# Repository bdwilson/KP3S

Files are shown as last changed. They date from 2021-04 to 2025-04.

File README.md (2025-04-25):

# warning: this repository has been deprecated as I no longer own a KP3S. 

# Kingroon KP3S 

<b>For general documentation/upgrades, please go here: https://bubba.org/kp3s</b>

# Marlin v2.x for Kingroon KP3S
Thanks to @olavgm for his work on 2.0.7 : https://github.com/olavgm/marlin-kp3s 

I've  changed the `configuration.h` and `configuration_adv.h` files and provided those in the different version folders/Marlin directories.

* Support for *BLTouch* has been added
* Babystepping added (but babystepping automatically updates z offset, so make sure to save once you have your z offset the way you want it). To use this, start a print, go into Settings -> Tune -> Z probe offset. 
* You'll need to turn your LCD sideways using [this](https://www.thingiverse.com/thing:4578390) print, or just turn your head sideways. I've chosen to do this since I use Octoprint and also have a magnetic camera mounted to where this LCD screen would overhang.  

A version <b>without</b> bltouch support has been added. I have not tested it,
but feel free to report any issues. It has mesh bed leveling enabled. You can
find it
[here](https://github.com/bdwilson/KP3S/tree/main/releases/2.1.1/no-bltouch).

## Installation
1. Follow the guidance here on installing and connecting: https://bubba.org/kp3s/3dTouch/
2. To install, copy Robin_nano.bin to in the root of an FAT32-formatted SD card.
3. You will need to adjust your Z-Offset (where your printer thinks the bed is in perspective to the extruder tip). Get your favorite bed leveling test print and utilize the Tune -> Z Probe Offset menu (only available after a print has been sent to the printer). You can also adjust this down to zero and slowly decrease it (go towards the negative) if you are worried about damaging your bed.

## Downloading a build
<b>These builds are built using the Titan settings below. If you have a different
setup, you will need to configure your parameters using repetier or
Ocotprint. The changes are mentioned below.</b>

* https://github.com/bdwilson/KP3S/tree/main/releases 

## Building your own.
Grab the configs from [here](https://github.com/bdwilson/KP3S/tree/main/releases) and then use the directions from [TH3D](https://support.th3dstudio.com/hc/downloads/unified-2-firmware/kingroon/kingroon-kp-3s-firmware-kingroon-v1-2-board/), but use this code. 

## Changes needed if you do not have a Titan extruder with mount on the right side 

### KP3S w/ Stock Extruder, BL Touch mounted on left of extruder
1. Mount BL Touch here: [male](https://github.com/bdwilson/KP3S/blob/main/files/BLtouch_Mount-left-male.stl?raw=true) - should be printed with supports & [female](https://github.com/bdwilson/KP3S/blob/main/files/BLtouch_Mount-left-female.stl?raw=true) (original files from here: https://www.thingiverse.com/thing:4609134)
2. Configure your ESTEPS Marlin Motion menu (Control -> Motion -> Steps/mm) -
https://marlinfw.org/docs/features/lcd_menu.html#steps/mm) and Z Probe Offset
via Marlin Prepare menu (Prepare -> Bed Leveling). You cannot change all of the
offsets via marlin, so you may need to use Repetier below. 
<b>You will set your z offset yourself via Marlin menu. If you don't use
the mount above, your offsets WILL be different and you'll need to compile your
own version.</b>
<pre>
#define DEFAULT_AXIS_STEPS_PER_UNIT   { 160, 160, 800, 185 }  // for stock extruder
#define NOZZLE_TO_PROBE_OFFSET { -27, 0, 0 }  // old extruder, mount on left
</pre>
or, you can do this via [Repetier](https://www.repetier.com/download-now/) or
Octoprint via termina:
<pre>
M92 X160 Y160 Z800 E185
M851 X-27 Y0 Z0
</pre>

### KP3S w/ Stock Extruder, BL Touch mounted on left of extruder 
1. Mount for BL Touch is [here](https://www.thingiverse.com/thing:4704668)
2. Configure your ESTEPS Marlin Motion menu (Control -> Motion -> Steps/mm) -
https://marlinfw.org/docs/features/lcd_menu.html#steps/mm) and Z Probe Offset
via Marlin Prepare menu (Prepare -> Bed Leveling). You cannot change all of the
offsets via marlin, so you may need to use Repetier below. 
<b>You will set your z offset yourself via Marlin menu. If you don't use
the mount above, your offsets WILL be different and you'll need to compile your
own version.</b>
<pre>
#define DEFAULT_AXIS_STEPS_PER_UNIT   { 160, 160, 800, 185 }  // for stock extruder
#define NOZZLE_TO_PROBE_OFFSET { -27, -1, 0 }  // old extruder, mount on left
</pre>
or, you can do this via [Repetier](https://www.repetier.com/download-now/) or
Octoprint via terminal:
<pre>
M92 X160 Y160 Z800 E185
M851 X-27 Y0 Z0
</pre>

### KP3S w/ Titan w/ metal enclosure, BL Touch mounted on right of extruder
1. Mount BL Touch using [this mount](https://www.thingiverse.com/thing:4816601)
2. You can download this version directly from me and do not need to make the
modifications below: https://github.com/bdwilson/KP3S/tree/main/releases 
3. Configure your ESTEPS Marlin Motion menu (Control -> Motion -> Steps/mm) -
https://marlinfw.org/docs/features/lcd_menu.html#steps/mm) and Z Probe Offset
via Marlin Prepare menu (Prepare -> Bed Leveling). You cannot change all of the
offsets via marlin, so you may need to use Repetier below. 
<b>You will set your z offset yourself via Marlin menu. If you don't use
the mount above, your offsets WILL be different and you'll need to compile your
own version.</b>
<pre>
#define DEFAULT_AXIS_STEPS_PER_UNIT   { 160, 160, 800, 905 } // for titan 
#define NOZZLE_TO_PROBE_OFFSET { 31, -1, 0 }  // titan extruder mount on right
</pre>
or, you can do this via [Repetier](https://www.repetier.com/download-now/) or
Octoprint via termina:
<pre>
M92 X160 Y160 Z800 E910
M851 X29 Y-1 Z-2.41
</pre>

[\<\< Back to Main KP3S site](https://bubba.org/kp3s)

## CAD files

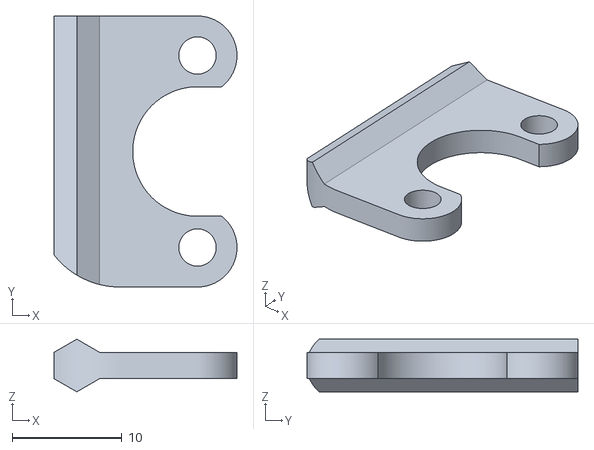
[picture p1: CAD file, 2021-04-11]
files/BLtouch_Mount-left-male.stl
16.7 x 24.7 x 4.80

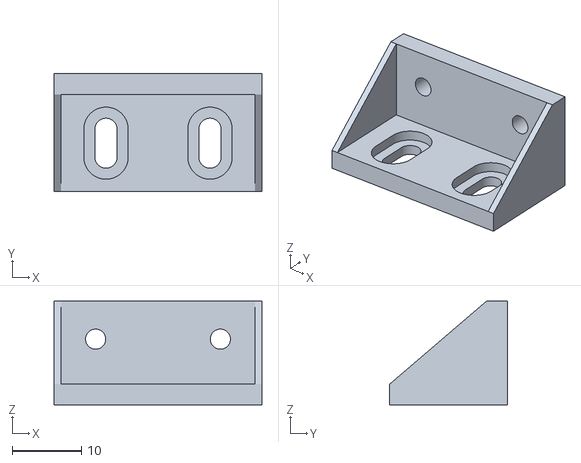
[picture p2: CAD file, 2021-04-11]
files/BLtouch_Mount-right.stl
30.0 x 17.0 x 15.0

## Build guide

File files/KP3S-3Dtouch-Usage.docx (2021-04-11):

KP3S-3Dtouch Using Method

1. Installation

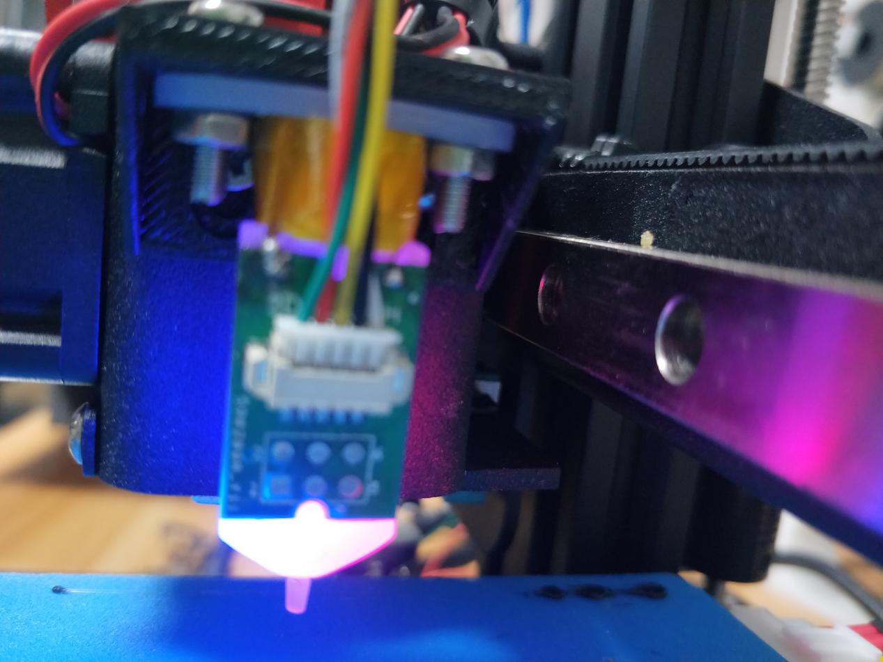
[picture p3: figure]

Fully connect adapter board to the profile. Otherwise,it will not trigger the endstop function if the probe rod of 3D touch is too low.

2. The setting wires of Auto Leveling Sensor
  2.1 Connect Leveling limit wire 2pin to Zmax, please note the order between black wire and white one.

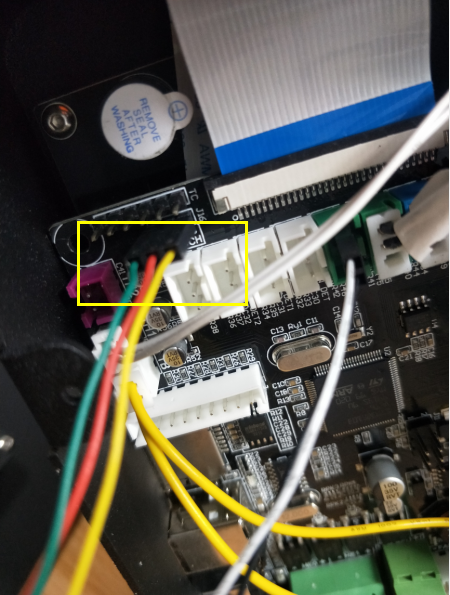
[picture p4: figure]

2.2The order of connecting Servo wires 3pin as following photo. Also, pay attention to the order of wires.

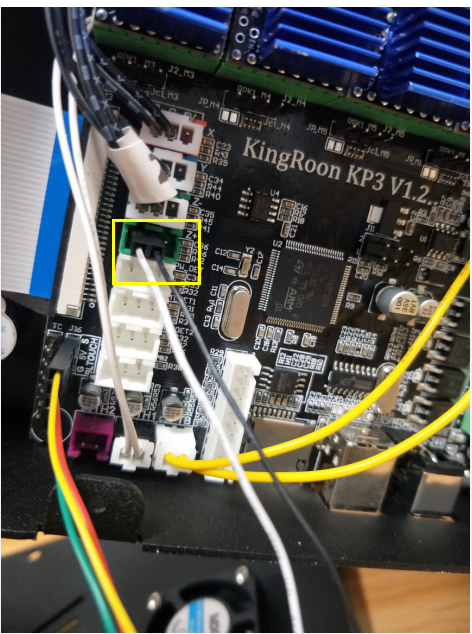
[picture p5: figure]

3.This is the setting of Configuration file

3.1 Change the mode as” cfg_leveling_mode” 1

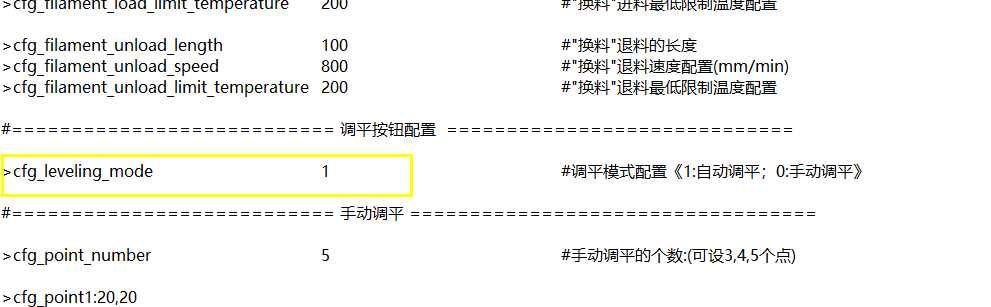
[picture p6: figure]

3.2 Setup it into Z Min_Probe_endstorp_inverting 0 # Z probe

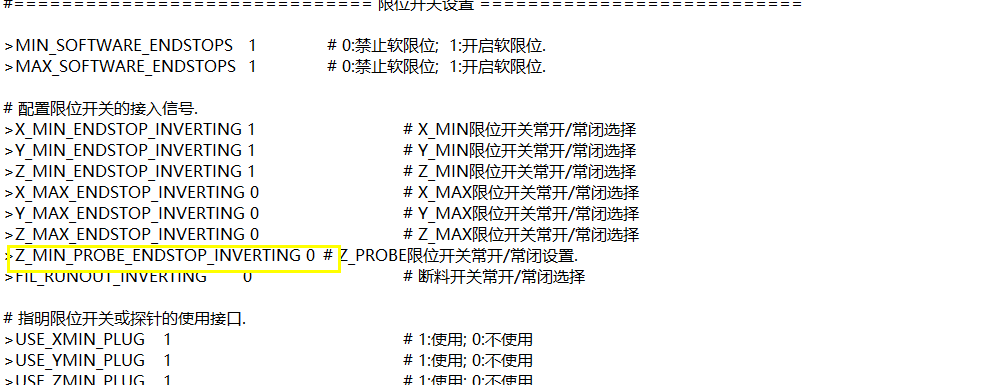
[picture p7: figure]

3.3 About the probe rob on ZmaxZ_min_probe_pin_mode 2

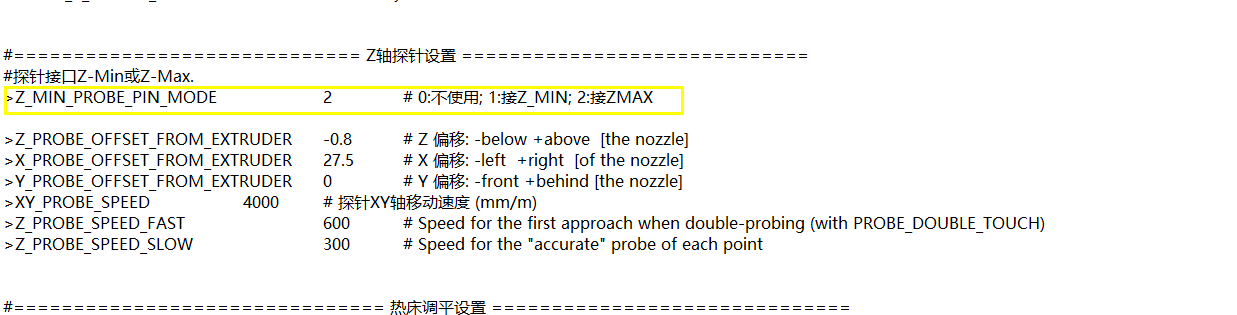
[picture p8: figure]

3.4 Setup the X, Y, Z axis offset ( If the distance between the extruder and the platform is too small when printing, then reduce the Z-axis offset value, otherwise, increase it.)

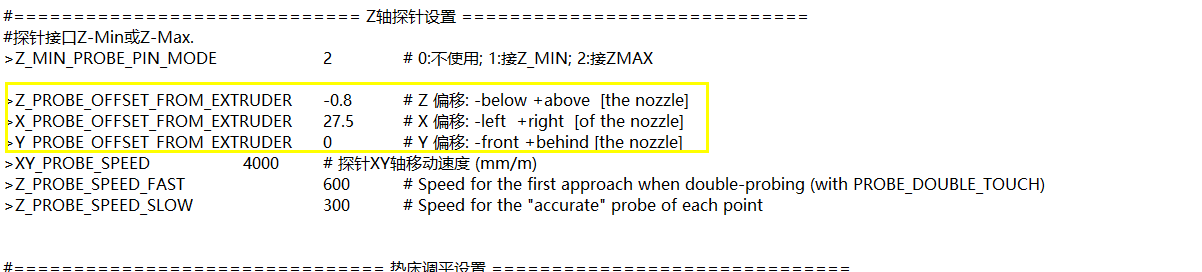
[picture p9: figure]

3.5 Set 3 point automatic leveling method

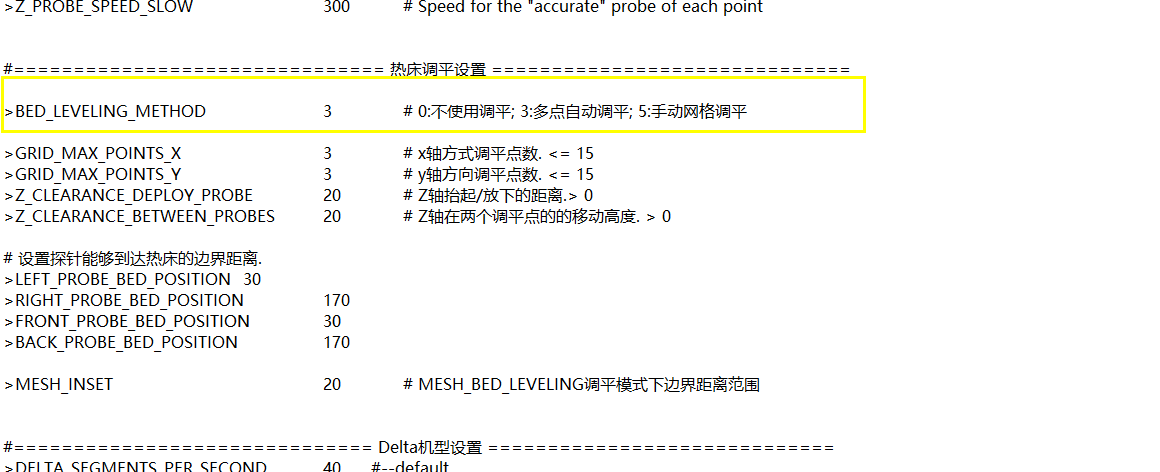
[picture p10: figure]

3.6 Leveling range

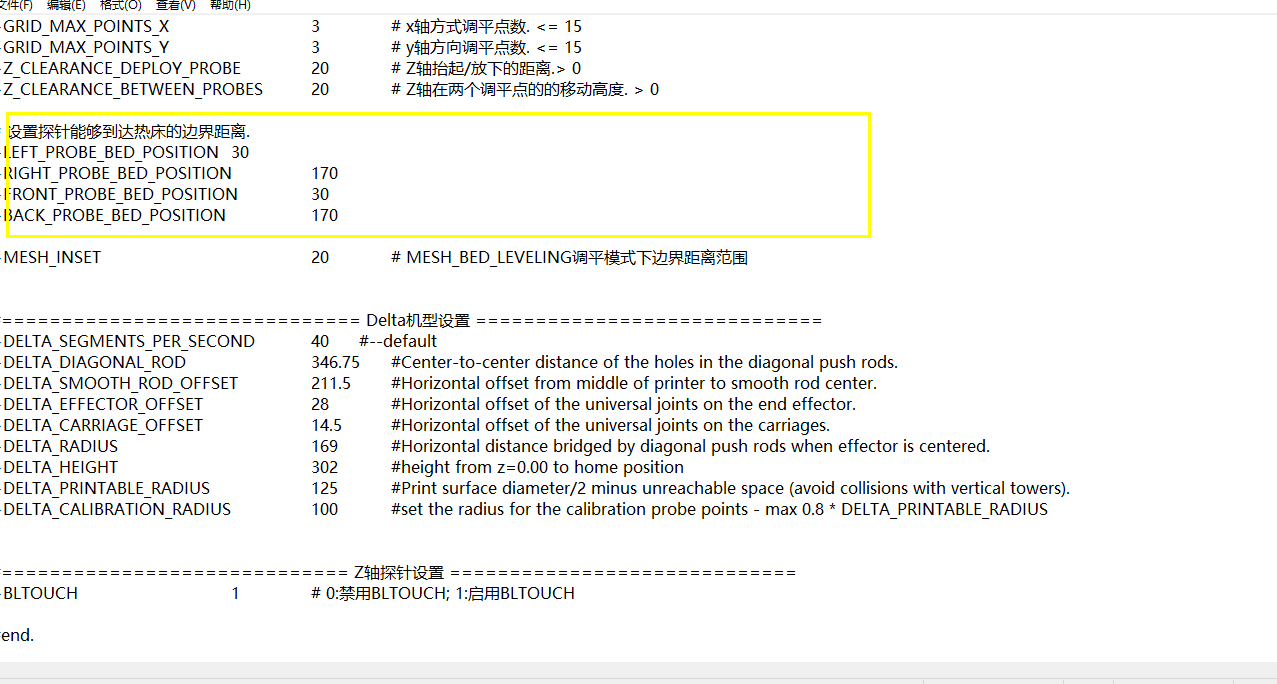
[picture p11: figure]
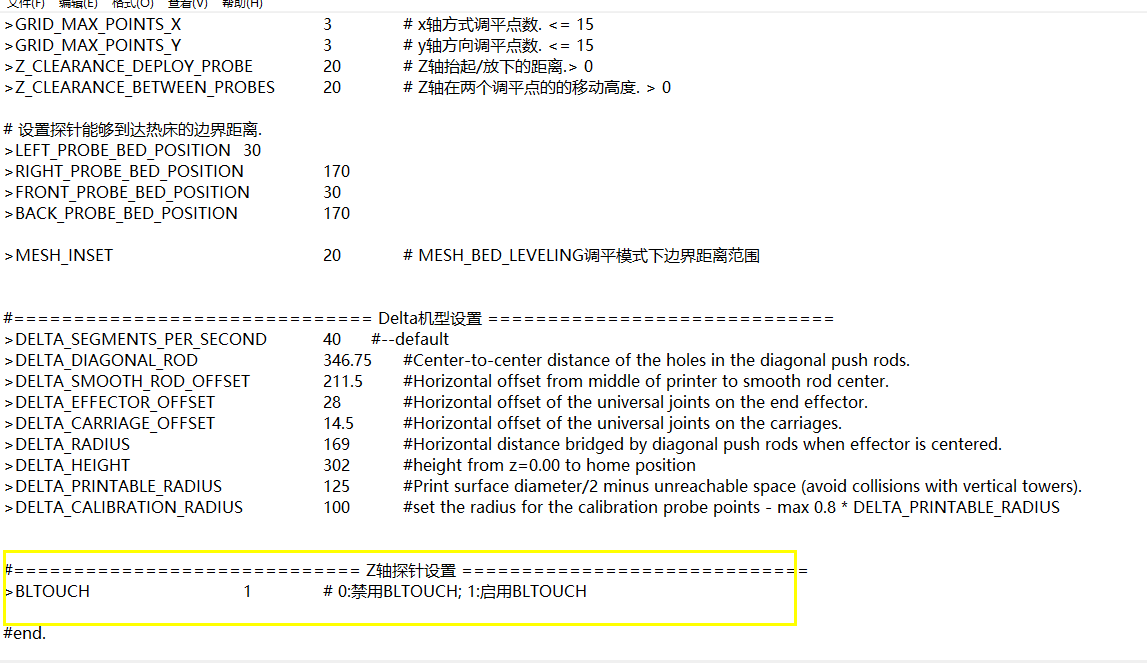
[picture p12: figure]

3.7 Turn on 3Dtouch

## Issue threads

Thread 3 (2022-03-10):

Can I use this firmware without BLTouch?

samuil4, 2022-03-10:
Hi,

I want to upload marlin to my KP3S but I don't have a BLTouch sensor. Can you provide a marlin build without the probe, or just the config files with the changes?

cfontes, 2022-04-06:
would be great to have a stock option pre build if possible!

brick2008, 2022-04-16:
The same question
Thanks

brick2008, 2022-04-16:
Require for build with stock option,Thanks.

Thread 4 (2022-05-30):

Z offset issue

navivfr, 2022-05-30:
I have this version
- TITAN extruder with metal protection
- Board 1.3 (303).
- BL touch.

Use this firmware :
https://github.com/bdwilson/KP3S/tree/main/releases/2.0.9.3

**ISSUE:** I cannot home the Z.
I can move it up, but never down...

bubbaiOS, 2022-05-30:
Does it work with an older version?

navivfr, 2022-05-31:
Same with the 3 versions
https://github.com/bdwilson/KP3S/tree/main/releases

Doing AUTO HOME (Option)
=> the X an Y doing well.
=> **But the Z rise up**
=> Then BL touch doing pin IN / OUT several times

And I cannot move the Z axis DOW with the panel control (only UP)

My Board is this one :
[https://www.digital360.solutions/KPS3.jpeg](url)

bdwilson, 2022-06-04:
It works fine for me. https://bubba.d.pr/fyy8Mm

navivfr, 2022-06-05:
Dear Wilson
You used the latest Marlin's version ?
The 'update procedure"  it's just to put the **robin_nano.bin** in the SD card and switch on the printer ?
Or i missed something ?

printCrab, 2022-06-17:
@navivfr You have the GD32F303 RET6 chip mcu

@bdwilson could this be an issue? some are STM32 some are GD32F303.

seems to be an issue with Ender3 pros
[https://github.com/MarlinFirmware/Marlin/issues/23806](url)

icreated4333, 2023-01-18:
@bdwilson, I noticed this issue of z not homing and fixed it, there was a minor error with your code where the z end stop needed to be inverted, I changed it from false to true as seen below. This is from configuration.h.

#define X_MIN_ENDSTOP_INVERTING true  // Set to true to invert the logic of the endstop.
#define Y_MIN_ENDSTOP_INVERTING true  // Set to true to invert the logic of the endstop.
#define Z_MIN_ENDSTOP_INVERTING true // Set to true to invert the logic of the endstop.  //this was initially false but after changing it to true, z-homing works. This should fix the issue.

#define I_MIN_ENDSTOP_INVERTING false // Set to true to invert the logic of the endstop.
#define J_MIN_ENDSTOP_INVERTING false // Set to true to invert the logic of the endstop.
#define K_MIN_ENDSTOP_INVERTING false // Set to true to invert the logic of the endstop.
#define U_MIN_ENDSTOP_INVERTING false // Set to true to invert the logic of the endstop.
#define V_MIN_ENDSTOP_INVERTING false // Set to true to invert the logic of the endstop.
#define W_MIN_ENDSTOP_INVERTING false // Set to true to invert the logic of the endstop.
#define X_MAX_ENDSTOP_INVERTING false // Set to true to invert the logic of the endstop.
#define Y_MAX_ENDSTOP_INVERTING false // Set to true to invert the logic of the endstop.
#define Z_MAX_ENDSTOP_INVERTING false // Set to true to invert the logic of the endstop.
#define I_MAX_ENDSTOP_INVERTING false // Set to true to invert the logic of the endstop.
#define J_MAX_ENDSTOP_INVERTING false // Set to true to invert the logic of the endstop.
#define K_MAX_ENDSTOP_INVERTING false // Set to true to invert the logic of the endstop.
#define U_MAX_ENDSTOP_INVERTING false // Set to true to invert the logic of the endstop.
#define V_MAX_ENDSTOP_INVERTING false // Set to true to invert the logic of the endstop.
#define W_MAX_ENDSTOP_INVERTING false // Set to true to invert the logic of the endstop.
#define Z_MIN_PROBE_ENDSTOP_INVERTING false // Set to true to invert the logic of the probe.

icreated4333, 2023-01-18:
I just realised someone has already posted this solution (@r3xpook) but its here if you need it!

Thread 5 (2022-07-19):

Using heater 1

rvntone, 2022-07-19:
Hi, I have been using the k3ps marlin firmware for a while, recently the MOSFET of the Heater 0 burnout, I want to know if there is a way to use heater 1 by default, I know it can be done by switching HEATER_0_PIN  and HEATER_1_PIN (at least I think that should work), but there are so many files that contain that constant pin*.h on src/pins/*/ folders, could anyone give me a hint on what to do?

rvntone, 2022-07-19:
If helps anyone, I succeded switching the HEATER_0_PIN and FAN1_PIN in the Marlin\src\pins\stm32f1\pins_MKS_ROBIN_NANO_common.h file :)

daniellezama, 2025-03-05:
hi only FAN1_PIN?

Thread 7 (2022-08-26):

Controll board/heatbreak fans

ims21, 2022-08-26:
Is possible controll fan on board and on heatbreak with temperature ? F.eg. heatbreak fan will run when is nozzle temperature > 50°C ?
Similar for board fan (or when are drivers in works only)

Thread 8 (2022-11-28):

MCU GD32 F303 compatible

navivfr, 2022-11-28:
Hello,

- I have a MCU GD32 F303 with BL Touch.
- I installed latest your firmware.

But seems to be an issue with Z axis : it doesn't want to go down (event with motion I cannot get it down).

When doing Bed leveling (after setting up Z offset):
•  X/Y axe move to home,
• But for Z homing , the head move to plate center, Z move up a bit
• probe try to nivel
then nothing...

I missed something ?

BR

navivfr, 2022-11-28:
Dear Wilson,

Thank you for replying...

I guess that is the trick, since I used the BL touch with the KP3S 'normal' firmware - so the BL touch is connected like Kingroon said...

But whet happen to the Z Stop then ? Is not used anymore ?

BR

bdwilson, 2022-11-29:
I had issues getting bltouch to work using their documentation. This was 2 years ago pre-titan. I will look at this the next time I make an update.

navivfr, 2022-11-29:
Hello,

thanks  a lot.. working now (I must read more carefully...)
Still some questions (sorry).
When auto level:
- How to select the matrix number point and range (borders)  ?
- when levelling - the extruder and bed warm up -> how to set those values  (i'm using mostly PETG so bed is 100°, and extruder I don't need to warm it up)
- How to set the approach speed and close level speed ?

With KP3S my robin_nano_cfg.txt look like this :

```
>GRID_MAX_POINTS_X	 5
>GRID_MAX_POINTS_Y 	5

>Z_CLEARANCE_DEPLOY_PROBE	2
>Z_CLEARANCE_BETWEEN_PROBES	10

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

>XY_PROBE_SPEED		9000
>Z_PROBE_SPEED_FAST	1000
>Z_PROBE_SPEED_SLOW 	60
```
BR

navivfr, 2022-12-03:
ok... i recompile all with my parameters...

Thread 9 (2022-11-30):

Wrong bed size for Marlin 2.1.1

justin-cotarla, 2022-11-30:
It seems the bed size is incorrectly defined for the Marlin 2.1.1 configurations. They are set as:

```
#define X_BED_SIZE 180
#define Y_BED_SIZE 172
```

I believe it should be:
```
#define X_BED_SIZE 180
#define Y_BED_SIZE 180
```

navivfr, 2022-11-30:
there is also an offset of -4mm for Y (I assume is way to make the 'runaway' for filament ?)
So should be like 176 ???

bdwilson, 2022-11-30:
It's so bltouch won't probe on a bed clip for a glass bed.

navivfr, 2022-12-03:
Was also hight wrong (120mm)
On what i understand he use Glass bed with clip, so he loose surface (PEI plate is fantastic BTW)
If you want i made a compilation upon is config with
- full dimension (180x180x180, but its possible ti wish it to 190 without any problem)
-  7 points bed levelling.
- Temp changement for auto level (i can compile on with you parameters)
-  Black backgroud and some color change

If you interest in it, But I don't know where to push it.

navivfr, 2022-12-03:
Hello, i created a folder with readme;. look like you have to validate ?
you can change the folder name to.
But i will be able to upload the .bin too
BR

bdwilson, 2022-12-03:
You'll have to do a pull request.

navivfr, 2022-12-05:
i dont know how to do this

tildebyte, 2023-01-19:
The weird thing is that the [header file in the repo](https://github.com/bdwilson/KP3S/blob/6018176fc410d797c8650996117976d38cbcc0fb/Marlin-2.1.1/Marlin/Configuration.h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) has 180, but the [header file in the release](https://github.com/bdwilson/KP3S/blob/8d84355710f861bb74633c35365581735ad88a11/releases/2.1.1/Configuration.h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) has 120.

I'm a total newb to this, so I don't know if the running firmware references the header file or not, but it seems like "what is the compiled firmware using" is the real question.

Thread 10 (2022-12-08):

marlin 2.1.1 inverted touch screen

R3xpook, 2022-12-08:
In the latest marlin 2.1.1 ( no bltouch ) the touch screen is inverted ...need to change line 3133 to #define TFT_ROTATION TFT_ROTATE_180

gmelikov, 2022-12-10:
Works for me without proposed changes. Honestly, I wanted to set `TFT_ROTATION TFT_ROTATE_180` exactly to rotate screen, but touch wasn't rotated so I used `TFT_NO_ROTATION`.

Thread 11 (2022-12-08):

marlin 2.1.1 inverted endstop

R3xpook, 2022-12-08:
In the no bl touch version marlin 2.1.1 line 1099
#define Z_MIN_ENDSTOP_INVERTING false
need to be changed into
#define Z_MIN_ENDSTOP_INVERTING true

ldhall1856, 2023-03-08:
Could someone help me with editing this?  I'm having the same issue but don't fully understand how to use auto build marlin and how to know how to build it without bltouch.

Nandox7, 2023-12-29:
You don't use Auto Build with this firmware, there is a note in the instructions.

As for the Z inverted, search for the line mentioned aboce in the configurations.h file and change from false to true.

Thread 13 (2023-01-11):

Non-bltouch 2.1.1

KnownOriginator, 2023-01-11:
Trying to use the 2.1.1 firmware for a my KP3S Pro (I changed the bed size to 210x210, hopefully that's fine), when I try to home the Z axis the gantry just kinda goes up a bit then stops. X homed fine, Y had to be reverse in firmware but that's fine. Z though, that's giving me a fit. I've reverted to the stock firmware from Kingroon for now.

icreated4333, 2023-01-18:
in configuration.h, change the z endstop from false to true. I had the same issue and this fixed it.

#define X_MIN_ENDSTOP_INVERTING true  // Set to true to invert the logic of the endstop.
#define Y_MIN_ENDSTOP_INVERTING true  // Set to true to invert the logic of the endstop.
#define Z_MIN_ENDSTOP_INVERTING true // Set to true to invert the logic of the endstop. // this was initially false

finland777, 2023-09-13:
> in configuration.h, change the z endstop from false to true. I had the same issue and this fixed it.
>
> #define X_MIN_ENDSTOP_INVERTING true // Set to true to invert the logic of the endstop. #define Y_MIN_ENDSTOP_INVERTING true // Set to true to invert the logic of the endstop. #define Z_MIN_ENDSTOP_INVERTING true // Set to true to invert the logic of the endstop. // this was initially false

Are you able to upload a robin_nano.bin file with the corrections? I'm struggling to learn how to build a new file with the correction.

anthonysedore, 2025-02-04:
[Robin_nano.zip](https://github.com/user-attachments/files/18649743/Robin_nano.zip)

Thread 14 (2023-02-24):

Tx/rx pin

pafftis, 2023-02-24:
Tell me how to find the pins rx and tx? I want to connect wemos d1 mini for our printer. I took 5v and gnd with a btouch pin, I need rx and tx to connect the esp3d project.
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

gstwrt, 2023-03-04:
I've been looking and trying to find where the additional usart pins are on the kingroon version of this board too.    No luck so far.

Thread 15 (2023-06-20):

Kingroon kp3s Y Axis inverted direction for Home

Adag10-jvs, 2023-06-20:

RJSDevel, 2023-08-07:
in my case for version 2.0.9.1, highest don't work

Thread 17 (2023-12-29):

KP3S Z Axis movement is inverted for Marlin 2.1.1

Nandox7, 2023-12-29:
Loaded the no bltouch 2.1.1 firmware version but the movement of the Z axis is inverted.

Will need to change setting and recompile firmware as this is not adjustable via the TFT or gCodes.

Nandox7, 2023-12-29:
Is the inverted Z endstop not the movement.

Closed 2023-12-29.

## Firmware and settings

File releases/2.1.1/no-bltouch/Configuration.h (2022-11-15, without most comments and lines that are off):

#pragma once
#define CONFIGURATION_H_VERSION 02010100
#define STRING_CONFIG_H_AUTHOR "(bdwilson)"             // Who made the changes.
#define SHOW_BOOTSCREEN
  #define MOTHERBOARD BOARD_MKS_ROBIN_NANO
#define SERIAL_PORT 3
#define BAUDRATE 115200
#define SERIAL_PORT_2 1
#define CUSTOM_MACHINE_NAME "KP3S"
#define X_DRIVER_TYPE  A4988
#define Y_DRIVER_TYPE  A4988
#define Z_DRIVER_TYPE  A4988
#define E0_DRIVER_TYPE A4988
#define EXTRUDERS 1
#define DEFAULT_NOMINAL_FILAMENT_DIA 1.75
#define TEMP_SENSOR_0 1
#define TEMP_SENSOR_1 0
#define TEMP_SENSOR_2 0
#define TEMP_SENSOR_3 0
#define TEMP_SENSOR_4 0
#define TEMP_SENSOR_5 0
#define TEMP_SENSOR_6 0
#define TEMP_SENSOR_7 0
#define TEMP_SENSOR_BED 1
#define TEMP_SENSOR_PROBE 0
#define TEMP_SENSOR_CHAMBER 0
#define TEMP_SENSOR_COOLER 0
#define TEMP_SENSOR_BOARD 0
#define TEMP_SENSOR_REDUNDANT 0
#define DUMMY_THERMISTOR_998_VALUE  25
#define DUMMY_THERMISTOR_999_VALUE 100
#if TEMP_SENSOR_IS_MAX_TC(0)
  #define MAX31865_SENSOR_OHMS_0      100 // (Ω) Typically 100 or 1000 (PT100 or PT1000)
  #define MAX31865_CALIBRATION_OHMS_0 430 // (Ω) Typically 430 for Adafruit PT100; 4300 for Adafruit PT1000
#endif
#if TEMP_SENSOR_IS_MAX_TC(1)
  #define MAX31865_SENSOR_OHMS_1      100
  #define MAX31865_CALIBRATION_OHMS_1 430
#endif
#if HAS_E_TEMP_SENSOR
  #define TEMP_RESIDENCY_TIME         10  // (seconds) Time to wait for hotend to "settle" in M109
  #define TEMP_WINDOW                  1  // (°C) Temperature proximity for the "temperature reached" timer
  #define TEMP_HYSTERESIS              3  // (°C) Temperature proximity considered "close enough" to the target
#endif
#if TEMP_SENSOR_BED
  #define TEMP_BED_RESIDENCY_TIME     10  // (seconds) Time to wait for bed to "settle" in M190
  #define TEMP_BED_WINDOW              1  // (°C) Temperature proximity for the "temperature reached" timer
  #define TEMP_BED_HYSTERESIS          3  // (°C) Temperature proximity considered "close enough" to the target
#endif
#if TEMP_SENSOR_CHAMBER
  #define TEMP_CHAMBER_RESIDENCY_TIME 10  // (seconds) Time to wait for chamber to "settle" in M191
  #define TEMP_CHAMBER_WINDOW          1  // (°C) Temperature proximity for the "temperature reached" timer
  #define TEMP_CHAMBER_HYSTERESIS      3  // (°C) Temperature proximity considered "close enough" to the target
#endif
#if TEMP_SENSOR_REDUNDANT
  #define TEMP_SENSOR_REDUNDANT_SOURCE    E1  // The sensor that will provide the redundant reading.
  #define TEMP_SENSOR_REDUNDANT_TARGET    E0  // The sensor that we are providing a redundant reading for.
  #define TEMP_SENSOR_REDUNDANT_MAX_DIFF  10  // (°C) Temperature difference that will trigger a print abort.
#endif
#define HEATER_0_MINTEMP   5
#define HEATER_1_MINTEMP   5
#define HEATER_2_MINTEMP   5
#define HEATER_3_MINTEMP   5
#define HEATER_4_MINTEMP   5
#define HEATER_5_MINTEMP   5
#define HEATER_6_MINTEMP   5
#define HEATER_7_MINTEMP   5
#define BED_MINTEMP        5
#define CHAMBER_MINTEMP    5
#define HEATER_0_MAXTEMP 275
#define HEATER_1_MAXTEMP 275
#define HEATER_2_MAXTEMP 275
#define HEATER_3_MAXTEMP 275
#define HEATER_4_MAXTEMP 275
#define HEATER_5_MAXTEMP 275
#define HEATER_6_MAXTEMP 275
#define HEATER_7_MAXTEMP 275
#define BED_MAXTEMP      150
#define CHAMBER_MAXTEMP  60
#define HOTEND_OVERSHOOT 15   // (°C) Forbid temperatures over MAXTEMP - OVERSHOOT
#define BED_OVERSHOOT    10   // (°C) Forbid temperatures over MAXTEMP - OVERSHOOT
#define COOLER_OVERSHOOT  2   // (°C) Forbid temperatures closer than OVERSHOOT
#define PIDTEMP          // See the PID Tuning Guide at https://reprap.org/wiki/PID_Tuning
#define BANG_MAX 255     // Limits current to nozzle while in bang-bang mode; 255=full current
#define PID_MAX BANG_MAX // Limits current to nozzle while PID is active (see PID_FUNCTIONAL_RANGE below); 255=full current
#define PID_K1 0.95      // Smoothing factor within any PID loop
    #define DEFAULT_Kp  14.91
    #define DEFAULT_Ki   1.09
    #define DEFAULT_Kd 51.00
#define PIDTEMPBED
#define MAX_BED_POWER 255 // limits duty cycle to bed; 255=full current
  #define DEFAULT_bedKp 94.42
  #define DEFAULT_bedKi 28.09
  #define DEFAULT_bedKd 490.97
#define MAX_CHAMBER_POWER 255 // limits duty cycle to chamber heater; 255=full current
  #define PID_FUNCTIONAL_RANGE 10 // If the temperature difference between the target temperature and the actual temperature
#define PREVENT_COLD_EXTRUSION
#define EXTRUDE_MINTEMP 170
#define PREVENT_LENGTHY_EXTRUDE
#define EXTRUDE_MAXLENGTH 1000
#define THERMAL_PROTECTION_HOTENDS // Enable thermal protection for all extruders
#define THERMAL_PROTECTION_BED     // Enable thermal protection for the heated bed
#define THERMAL_PROTECTION_CHAMBER // Enable thermal protection for the heated chamber
#define THERMAL_PROTECTION_COOLER  // Enable thermal protection for the laser cooling
#define USE_XMIN_PLUG
#define USE_YMIN_PLUG
#define USE_ZMIN_PLUG
#define ENDSTOPPULLUPS
#define X_MIN_ENDSTOP_INVERTING true  // Set to true to invert the logic of the endstop.
#define Y_MIN_ENDSTOP_INVERTING true  // Set to true to invert the logic of the endstop.
#define Z_MIN_ENDSTOP_INVERTING false // Set to true to invert the logic of the endstop.
#define I_MIN_ENDSTOP_INVERTING false // Set to true to invert the logic of the endstop.
#define J_MIN_ENDSTOP_INVERTING false // Set to true to invert the logic of the endstop.
#define K_MIN_ENDSTOP_INVERTING false // Set to true to invert the logic of the endstop.
#define U_MIN_ENDSTOP_INVERTING false // Set to true to invert the logic of the endstop.
#define V_MIN_ENDSTOP_INVERTING false // Set to true to invert the logic of the endstop.
#define W_MIN_ENDSTOP_INVERTING false // Set to true to invert the logic of the endstop.
#define X_MAX_ENDSTOP_INVERTING false // Set to true to invert the logic of the endstop.
#define Y_MAX_ENDSTOP_INVERTING false // Set to true to invert the logic of the endstop.
#define Z_MAX_ENDSTOP_INVERTING false // Set to true to invert the logic of the endstop.
#define I_MAX_ENDSTOP_INVERTING false // Set to true to invert the logic of the endstop.
#define J_MAX_ENDSTOP_INVERTING false // Set to true to invert the logic of the endstop.
#define K_MAX_ENDSTOP_INVERTING false // Set to true to invert the logic of the endstop.
#define U_MAX_ENDSTOP_INVERTING false // Set to true to invert the logic of the endstop.
#define V_MAX_ENDSTOP_INVERTING false // Set to true to invert the logic of the endstop.
#define W_MAX_ENDSTOP_INVERTING false // Set to true to invert the logic of the endstop.
#define Z_MIN_PROBE_ENDSTOP_INVERTING false // Set to true to invert the logic of the probe.
#define ENDSTOP_INTERRUPTS_FEATURE
#define DEFAULT_AXIS_STEPS_PER_UNIT   { 160, 160, 800, 848 }
#define DEFAULT_MAX_FEEDRATE          { 200, 200, 4, 100 }
#define DEFAULT_MAX_ACCELERATION      { 1000, 1000, 100, 1000 }
#define DEFAULT_ACCELERATION          1000    // X, Y, Z and E acceleration for printing moves
#define DEFAULT_RETRACT_ACCELERATION  1000    // E acceleration for retracts
#define DEFAULT_TRAVEL_ACCELERATION   1000    // X, Y, Z acceleration for travel (non printing) moves
#define CLASSIC_JERK
  #define DEFAULT_XJERK 15.0
  #define DEFAULT_YJERK 15.0
  #define DEFAULT_ZJERK  0.4
#define DEFAULT_EJERK    5.0  // May be used by Linear Advance
#define S_CURVE_ACCELERATION
#define Z_MIN_PROBE_USES_Z_MIN_ENDSTOP_PIN
#define NOZZLE_TO_PROBE_OFFSET { 28, 2, -3.57 }
#define PROBING_MARGIN 5
#define XY_PROBE_FEEDRATE (133*60)
#define Z_PROBE_FEEDRATE_FAST (4*60)
#define Z_PROBE_FEEDRATE_SLOW (Z_PROBE_FEEDRATE_FAST / 2)
#define Z_CLEARANCE_DEPLOY_PROBE   10 // Z Clearance for Deploy/Stow
#define Z_CLEARANCE_BETWEEN_PROBES  5 // Z Clearance between probe points
#define Z_CLEARANCE_MULTI_PROBE     5 // Z Clearance between multiple probes
#define Z_AFTER_PROBING           5   // Z position after probing is done
#define Z_PROBE_LOW_POINT          -1 // Farthest distance below the trigger-point to go before stopping
#define Z_PROBE_OFFSET_RANGE_MIN -10
#define Z_PROBE_OFFSET_RANGE_MAX 10
#define X_ENABLE_ON 0
#define Y_ENABLE_ON 0
#define Z_ENABLE_ON 0
#define E_ENABLE_ON 0 // For all extruders
#define DISABLE_X false
#define DISABLE_Y false
#define DISABLE_Z false
#define DISABLE_E false             // Disable the extruder when not stepping
#define DISABLE_INACTIVE_EXTRUDER   // Keep only the active extruder enabled
#define INVERT_X_DIR false
#define INVERT_Y_DIR false
#define INVERT_Z_DIR true
#define INVERT_E0_DIR true
#define INVERT_E1_DIR false
#define INVERT_E2_DIR false
#define INVERT_E3_DIR false
#define INVERT_E4_DIR false
#define INVERT_E5_DIR false
#define INVERT_E6_DIR false
#define INVERT_E7_DIR false
#define Z_HOMING_HEIGHT  4        // (mm) Minimal Z height before homing (G28) for Z clearance above the bed, clamps, ...
#define Z_AFTER_HOMING  10        // (mm) Height to move to after homing Z
#define X_HOME_DIR -1
#define Y_HOME_DIR -1
#define Z_HOME_DIR -1
#define X_BED_SIZE 180
#define Y_BED_SIZE 172
#define X_MIN_POS 0
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

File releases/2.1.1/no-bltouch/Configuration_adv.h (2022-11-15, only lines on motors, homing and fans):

#define E0_AUTO_FAN_PIN -1
#define E1_AUTO_FAN_PIN -1
#define E2_AUTO_FAN_PIN -1
#define E3_AUTO_FAN_PIN -1
#define E4_AUTO_FAN_PIN -1
#define E5_AUTO_FAN_PIN -1
#define E6_AUTO_FAN_PIN -1
#define E7_AUTO_FAN_PIN -1
#define CHAMBER_AUTO_FAN_PIN -1
#define COOLER_AUTO_FAN_PIN -1
#define HOMING_BUMP_MM      { 5, 5, 2 }       // (linear=mm, rotational=°) Backoff from endstops after first bump
#define HOMING_BUMP_DIVISOR { 2, 2, 4 }       // Re-Bump Speed Divisor (Divides the Homing Feedrate)
#define MICROSTEP_MODES { 16, 16, 16, 16, 16, 16 } // [1,2,4,8,16]
#define ADVANCED_PAUSE_FEATURE
  #define ADVANCED_PAUSE_PURGE_FEEDRATE        3  // (mm/s) Extrude feedrate (after loading). Should be slower than load feedrate.
  #define ADVANCED_PAUSE_PURGE_LENGTH         50  // (mm) Length to extrude after loading.
  #define ADVANCED_PAUSE_RESUME_PRIME          0  // (mm) Extra distance to prime nozzle after returning from park.

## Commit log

2021-04-02 power supply
2021-04-11 3d touch updates
    [BLtouch_Mount-left-female.stl, BLtouch_Mount-left-male.stl, BLtouch_Mount-right.stl]
2021-05-18 add marlin kp3s info
    [Configuration.h, Configuration_adv.h]
2021-05-19 update bltouch left mount
    [BLtouch_Mount-left-female.stl]
2021-06-30 adding updated bin for 2.0.8.1
    [Configuration.h, Configuration_adv.h]
2022-11-15 Adding 2.1.1; added Tramming wizard
    [Configuration.h, Configuration_adv.h, esp32.csv]
2022-11-15 added a version without bltouch for 2.1.1
    [Configuration.h, Configuration_adv.h]

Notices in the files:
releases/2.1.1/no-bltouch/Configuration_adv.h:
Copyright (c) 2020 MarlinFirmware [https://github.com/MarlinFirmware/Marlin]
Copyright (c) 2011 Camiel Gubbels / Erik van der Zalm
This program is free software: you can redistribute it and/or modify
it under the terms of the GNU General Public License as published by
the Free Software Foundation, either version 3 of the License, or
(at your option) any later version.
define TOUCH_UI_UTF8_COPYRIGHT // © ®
